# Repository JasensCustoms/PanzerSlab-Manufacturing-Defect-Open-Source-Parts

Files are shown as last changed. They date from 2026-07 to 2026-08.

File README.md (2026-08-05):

<p align="center">
  Jasen's Customs Logo
</p>

# Panzer SLAB — Manufacturing Defect Compatible Parts

Compatible replacement parts for the Panzer SLAB manufacturing defect. This repository holds basic PCB outlines, cable pinouts, and related files. You are welcome to fix errors, add context, and contribute to the repo.

## What's in This Repo

- `Main PCB/` — main PCB design files
- `Plexi Overlay/` — plexi overlay cut file / art template (all SLABs)
- `AUX PCB Files/` — AUX PCB design and production files
- `USB C PCB Files/` — USB-C PCB design and production files
- `3D Printed Parts/` — 3D-printable parts (main PCB fix spacers and taller aux button)

## Community & Discussion

Questions, ideas, or just want to talk builds? Join the Jasen's Customs Discord: [discord.gg/UJmNMunTqa](https://discord.gg/UJmNMunTqa)

## License — Personal, Non-Commercial Use Only

Copyright © 2026 Jasen Hicks ([www.JasensCustoms.com](https://www.JasensCustoms.com)). All rights reserved.

These designs are provided **solely for personal, private, non-commercial use.** You may build units for yourself, modify the designs for your own projects, and share the unmodified files (with attribution and the license intact). You may **not** sell parts, kits, units, or derivatives, manufacture for profit, or use these files commercially in any way.

Full terms — including the **No Warranty** and **No Support** notices — are in [LICENSE.md](LICENSE.md). By downloading, copying, or using any file in this repository, you agree to them.

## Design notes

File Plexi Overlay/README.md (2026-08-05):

# Plexi Overlay

Plexi overlay cut file for the Panzer SLAB. **Works on all SLABs.**

## What's in This Folder

- `panzer-slab.svg` — full overlay outline: all button openings, case outline, and mounting holes

## Material

Use **1.5mm (1/16") plexi/acrylic**.

## Usage

The file works two ways:

- **Direct cutting** — send it straight to a laser cutter or CNC as-is.
- **Art template** — use it as the template layer in your design software to line artwork up with the button openings and case outline before cutting.

## License & Community

Part of the [Panzer SLAB — Manufacturing Defect Compatible Parts](../README.md) repository. Provided for **personal, non-commercial use only** — full terms in [LICENSE.md](../LICENSE.md). Questions? Join the Jasen's Customs Discord: [discord.gg/UJmNMunTqa](https://discord.gg/UJmNMunTqa)

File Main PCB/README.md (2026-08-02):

# Main PCB

The main PCB has the critical placement of the Brook PCB, USB output, AUX PCB connections, OLED connections, and LEDs. Everything is unrouted. The files are provided in Fusion Archive Format. Placement of MX sockets should be at the center of each circle on the PCB to ensure fitment.

## What's in This Folder

- `slab-main-pcb-open-source-unrouted.f3z` — unrouted board, Fusion Archive Format
- `slab-main-pcb-open-source-board-mx-routed.fbrd` — routed MX version
- `slab-main-pcb-open-source-board_2026-07-29.zip` — production files
- `slab-main-pcb-open-source-board_bom.csv` / `slab-main-pcb-open-source-board_cpl.csv` — BOM and component placement (CPL) files

## Parts List (BOM)

Complete parts list from `slab-main-pcb-open-source-board_bom.csv` (LCSC part numbers included for ordering). Use the CPL file for component placement.

| Qty | Part | Designators | Footprint | LCSC # |
|---|---|---|---|---|
| 15 | 0.1µF capacitor | C1–C4, C6–C15, C20 | 0402 | C60474 |
| 15 | SK6812MINI reverse-mount RGB LED | U$4–U$18 | C5149201 | C5149201 |
| 15 | Kailh hot-swap switch socket | SW1–SW15 | SWITCH_SOCKET | C5156480 |
| 2 | 22Ω resistor | R5, R6 | 0805 | C17561 |
| 2 | 500Ω resistor | R3, R4 | 0402 | C227124 |
| 2 | 2x4 header | U$1, U$2 | 2X4 | C225289 |
| 1 | 1x4 right-angle header | JP2 | 1X04/90 | C32713263 |
| 1 | MF-SMDF050 resettable fuse | U$19 | MF-SMDF050 | C210839 |
| 1 | JST S4B-PH-SM4-TB connector (PH, 4-pin, side-entry SMT) | X1 | S4B-PH-SM4-TB | C265102 |
| 1 | USB-302S USB connector | U$20 | USB-302S | C112455 |

### Additional Parts Not on the BOM

- **4x 1x11 2.54mm pitch low-profile machine pin sockets** — required for the Brook PCB mounting area.

## Routed MX Version

> **UNTESTED AS OF 07/29/2026** — please manufacture at your own risk. Download the files and check them yourself as a second check.

Includes a USB key so if someone ever publishes a GP2040 board in the same Gen5X footprint, you can make use of the auth key functionality.

Routed MX main PCB, top view

Routed MX main PCB, bottom view

## License & Community

Part of the [Panzer SLAB — Manufacturing Defect Compatible Parts](../README.md) repository. Provided for **personal, non-commercial use only** — full terms in [LICENSE.md](../LICENSE.md). Questions? Join the Jasen's Customs Discord: [discord.gg/UJmNMunTqa](https://discord.gg/UJmNMunTqa)

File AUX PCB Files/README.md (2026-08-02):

# AUX PCB Files

Design and production files for the SLAB AUX PCB.

## What's in This Folder

- `slab-aux-pcb.brd` / `slab-aux-pcb.sch` — Autodesk EagleCAD board and schematic files
- `slab-aux-pcb_2025-09-11.zip` — production files

## License & Community

Part of the [Panzer SLAB — Manufacturing Defect Compatible Parts](../README.md) repository. Provided for **personal, non-commercial use only** — full terms in [LICENSE.md](../LICENSE.md). Questions? Join the Jasen's Customs Discord: [discord.gg/UJmNMunTqa](https://discord.gg/UJmNMunTqa)

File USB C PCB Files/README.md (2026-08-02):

# USB C PCB Files

Design and production files for the SLAB USB-C PCB.

## What's in This Folder

- `usb-c-pcb.brd` / `usb-c-pcb.sch` — Autodesk EagleCAD board and schematic files
- `usb-c-pcb_2025-09-19.zip` — production files

## License & Community

Part of the [Panzer SLAB — Manufacturing Defect Compatible Parts](../README.md) repository. Provided for **personal, non-commercial use only** — full terms in [LICENSE.md](../LICENSE.md). Questions? Join the Jasen's Customs Discord: [discord.gg/UJmNMunTqa](https://discord.gg/UJmNMunTqa)

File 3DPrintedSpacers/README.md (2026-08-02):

# 3D Printed Spacers

3D printed spacers that fit over the machined posts on the case to space the main PCB at the correct distance from the top panel.

## What's in This Folder

- `SLABMainPCBFixSpacers-V1.0.3MF` — all spacer parts in a single 3MF file (V1.0)

## Printing Guidance

Print in **PETG** with thick walls — 4 wall loops works great.

Print the following quantities:

- **2x** D-shaped spacers
- **1x** irregularly shaped circle spacer
- **7x** circle spacers

## License & Community

Part of the [Panzer SLAB — Manufacturing Defect Compatible Parts](../README.md) repository. Provided for **personal, non-commercial use only** — full terms in [LICENSE.md](../LICENSE.md). Questions? Join the Jasen's Customs Discord: [discord.gg/UJmNMunTqa](https://discord.gg/UJmNMunTqa)

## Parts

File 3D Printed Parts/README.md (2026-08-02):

# 3D Printed Parts

3D-printable parts for the Panzer SLAB manufacturing defect fix.

## What's in This Folder

- `SLABMainPCBFixSpacers-V1.0.3MF` — main PCB fix spacers, all parts in a single 3MF file (V1.0)
- `SLAB - AuxButtonTaller.STL` — taller aux button

## Spacers

The spacers fit over the machined posts on the case to space the main PCB at the correct distance from the top panel.

Print in **PETG** with thick walls — 4 wall loops works great.

Print the following quantities:

- **2x** D-shaped spacers
- **1x** irregularly shaped circle spacer
- **7x** circle spacers

## License & Community

Part of the [Panzer SLAB — Manufacturing Defect Compatible Parts](../README.md) repository. Provided for **personal, non-commercial use only** — full terms in [LICENSE.md](../LICENSE.md). Questions? Join the Jasen's Customs Discord: [discord.gg/UJmNMunTqa](https://discord.gg/UJmNMunTqa)

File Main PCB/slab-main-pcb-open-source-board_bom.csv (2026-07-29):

Comment | Designator | Footprint | LCSC Part #
 | JP2 | 1X04/90 | C32713263
.1uF | C1 C2 C3 C4 C6 C7 C8 C9 C10 C11 C12 C13 C14 C15 C20 | C0402K | C60474
2X4 | U$1 U$2 | 2X4 | C225289
22 | R5 R6 | R0805 | C17561
500 | R3 R4 | R0402 | C227124
C5149201-SK6812MINI | U$4 U$5 U$6 U$7 U$8 U$9 U$10 U$11 U$12 U$13 U$14 U$15 U$16 U$17 U$18 | C5149201-REVERSEMOUNTLED | C5149201
KAILH_SWITCH_SOCKET | SW1 SW2 SW3 SW4 SW5 SW6 SW7 SW8 SW9 SW10 SW11 SW12 SW13 SW14 SW15 | SWITCH_SOCKET | C5156480
MF-SMDF050 | U$19 | MF-SMDF050 | C210839
S4B-PH-SM4-TB | X1 | S4B-PH-SM4-TB | C265102
USB-302S | U$20 | USB-302S | C112455

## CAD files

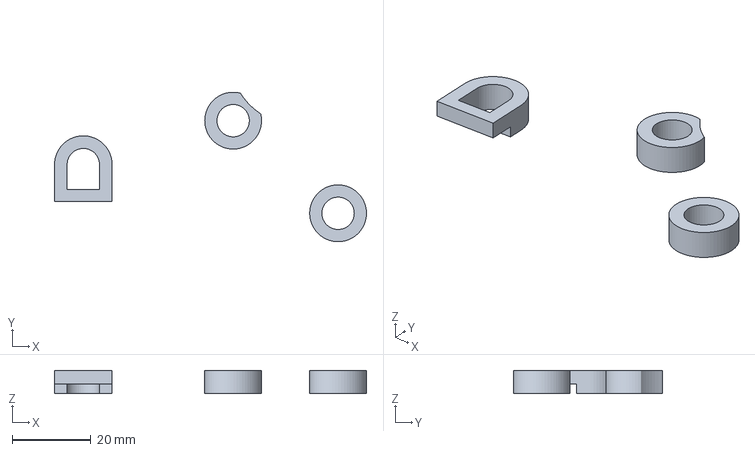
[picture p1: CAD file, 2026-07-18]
3D Printed Parts/SLABMainPCBFixSpacers-V1.0.3MF
79.0 x 37.9 x 5.90 mm

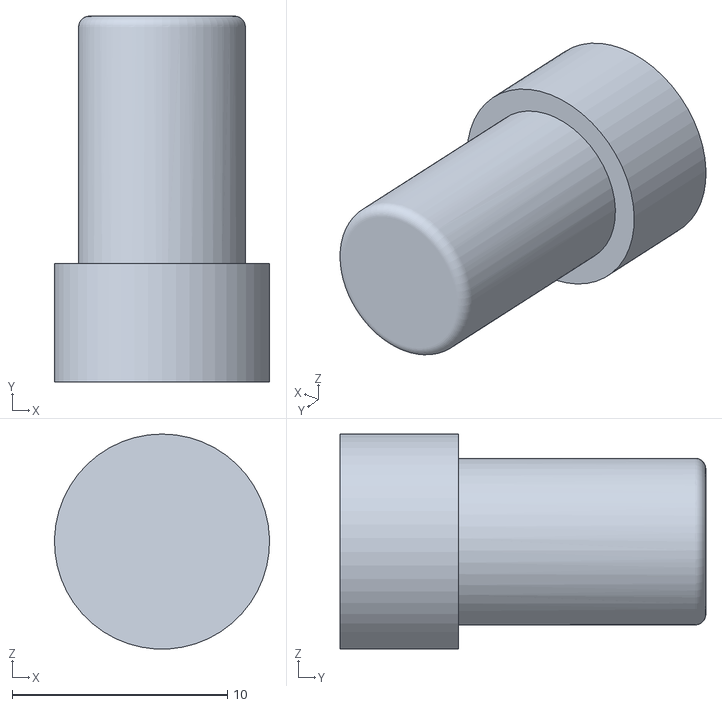
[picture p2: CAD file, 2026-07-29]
3D Printed Parts/SLAB - AuxButtonTaller.STL
9.99 x 17.0 x 9.99

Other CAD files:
Main PCB/slab-main-pcb-open-source-unrouted.f3z

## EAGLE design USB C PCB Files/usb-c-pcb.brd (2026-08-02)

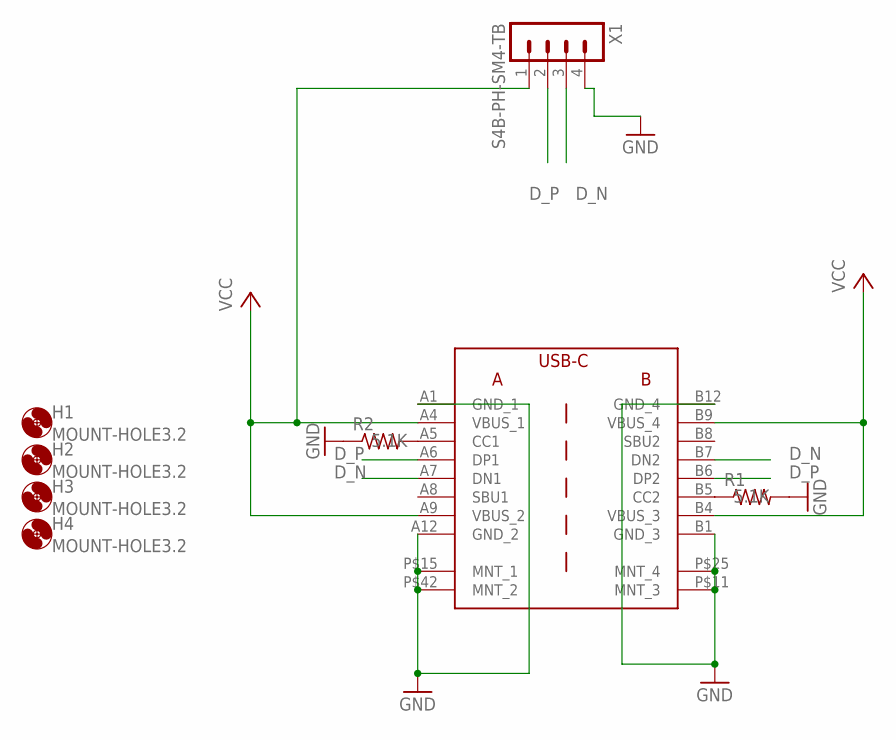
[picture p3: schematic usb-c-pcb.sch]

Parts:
H1, H2, H3, H4: MOUNT-HOLE3.2; 3,2
R1, R2: 5.1K; R0402
U$1: USB_TAYPE_C_16P
X1: S4B-PH-SM4-TB

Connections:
D_N: U$1.A7 (DN1), U$1.B7 (DN2), X1.3
D_P: U$1.A6 (DP1), U$1.B6 (DP2), X1.2
GND: R1.2, R2.1, U$1.A1 (GND_1), U$1.A12 (GND_2), U$1.B1 (GND_3), U$1.B12 (GND_4), U$1.P$11 (MNT_3), U$1.P$15 (MNT_1), U$1.P$25 (MNT_4), U$1.P$42 (MNT_2), X1.4
unnamed: R1.1, U$1.B5 (CC2)
unnamed: R2.2, U$1.A5 (CC1)
VCC: U$1.A4 (VBUS_1), U$1.A9 (VBUS_2), U$1.B4 (VBUS_3), U$1.B9 (VBUS_4), X1.1

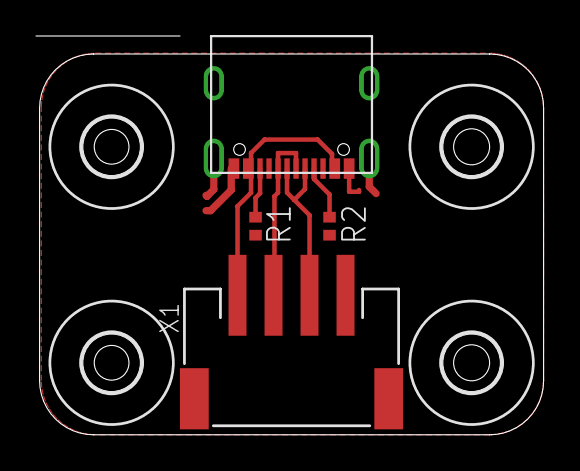
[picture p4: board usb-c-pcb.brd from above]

Board: 2 copper layers, 28.2 x 22.2 mm, 8 parts (0 on the bottom side), 6 nets.

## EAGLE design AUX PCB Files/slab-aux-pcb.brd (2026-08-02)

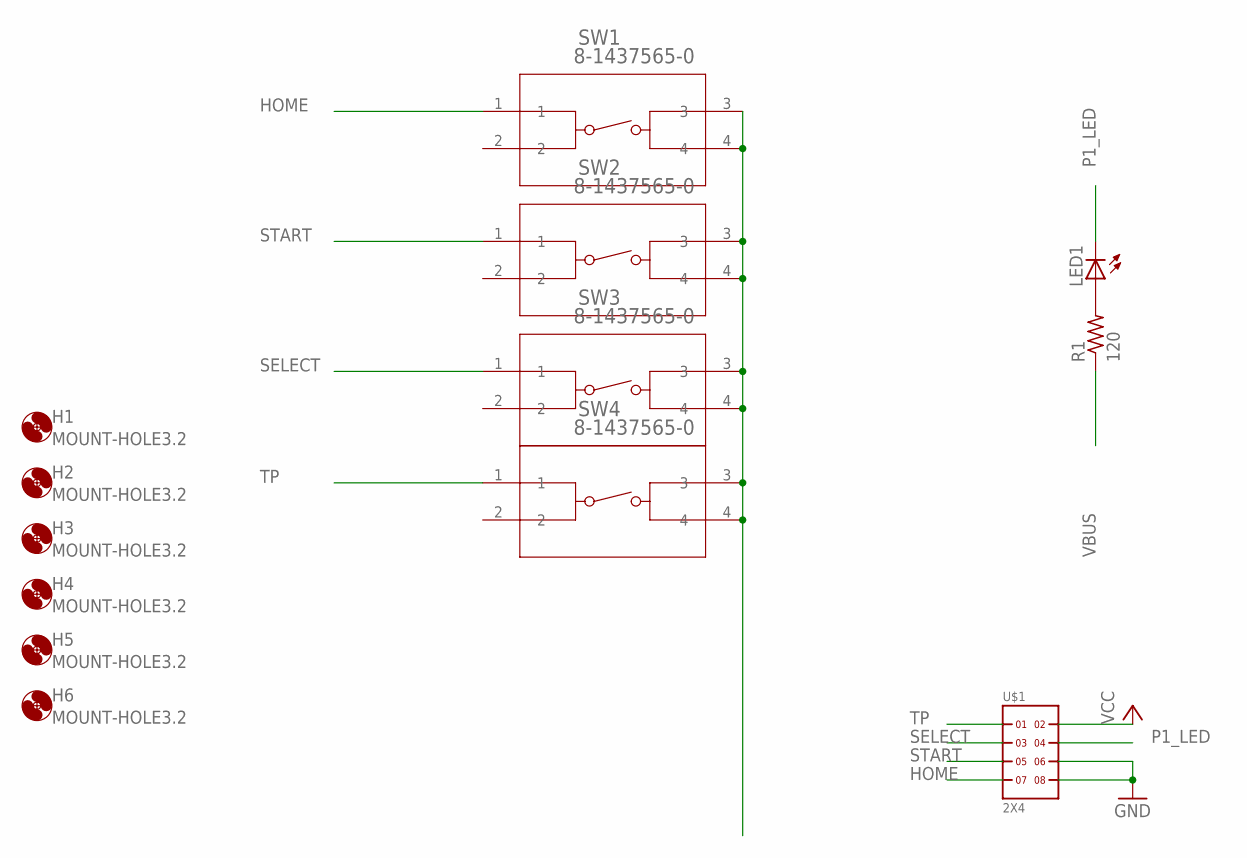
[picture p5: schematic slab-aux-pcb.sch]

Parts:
H1, H2, H3, H4, H5, H6: MOUNT-HOLE3.2; 3,2
LED1: LEDCHIP-LED0603; CHIP-LED0603
R1: 120; R0603
SW1, SW2, SW3, SW4: 8-1437565-0; SW4_1437565
U$1: 2X4

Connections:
GND: SW1.3, SW1.4, SW2.3, SW2.4, SW3.3, SW3.4, SW4.3, SW4.4, U$1.6, U$1.8
HOME: SW1.1, U$1.7
unnamed: LED1.A, R1.2
P1_LED: LED1.C, U$1.4
SELECT: SW3.1, U$1.3
START: SW2.1, U$1.5
TP: SW4.1, U$1.1
VBUS: R1.1, U$1.2

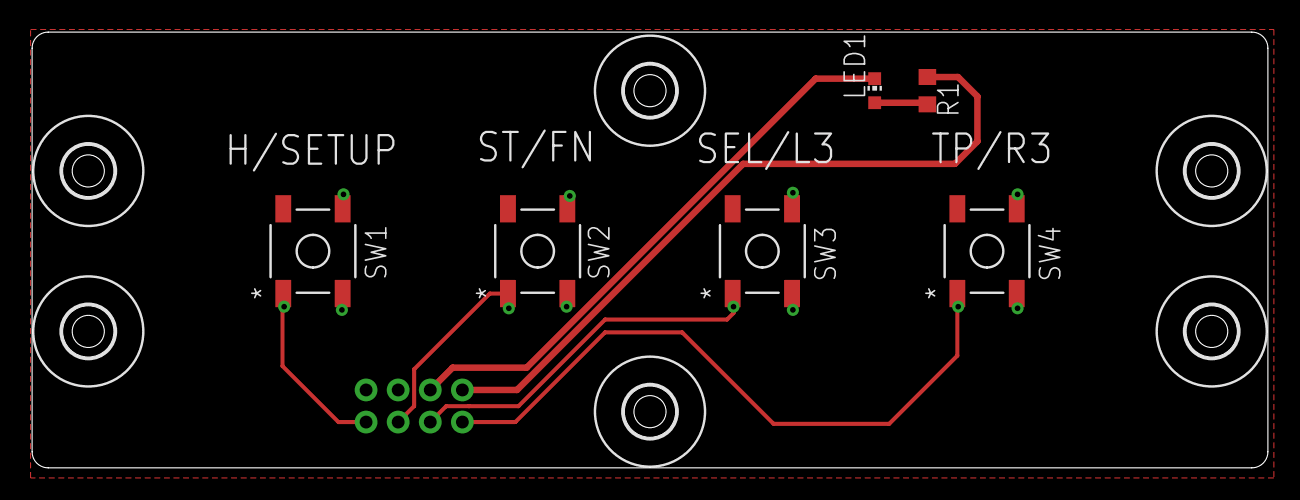
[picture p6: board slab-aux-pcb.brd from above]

Board: 2 copper layers, 77.0 x 27.2 mm, 13 parts (1 on the bottom side), 8 nets.

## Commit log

2026-07-18 Add readme for main PCB details and connections
    Added a description for the main PCB layout and connections.
2026-07-18 Add description for 3D printed spacers
2026-07-18 Update readme with printing specifications
    Added printing material and wall thickness recommendation.
2026-07-18 Add files via upload
    Base spacers that need to be 3D printed in 3MF format.
    [SLABMainPCBFixSpacers-V1.0.3MF]
2026-07-18 Update readme with spacer printing instructions
    Added printing instructions for 3D printed spacers.
2026-07-29 Add files via upload
    5mm taller AUX buttons to support mis-manufactured SLAB cases.
    [SLAB - AuxButtonTaller.STL]
2026-07-29 Add files via upload
    Fusion PCB file archive, BOM, CPL, and JLC PCB Gerber Files.
    [slab-main-pcb-open-source-board_bom.csv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]
2026-08-02 Add structured README.md files for each subfolder
    Consistent with the repo-wide README style: contents list, build/print
    guidance, and license/community footer.
    Claude-Session: https://claude.ai/code/session_013JLHN2qqf5r5F5bnh4qKFf
2026-08-02 Add AUX PCB and USB-C PCB files; consolidate 3D printed parts
    New AUX PCB Files and USB C PCB Files folders with EagleCAD and
    production files. 3D-printable parts (spacers + taller aux button)
    consolidated into 3D Printed Parts, replacing 3DPrintedSpacers and
    the root STL. README.md added for each new folder; root README
    updated to match.
    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
    [SLAB - AuxButtonTaller.STL, SLABMainPCBFixSpacers-V1.0.3MF, slab-aux-pcb.brd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]
2026-08-02 Add complete parts list to Main PCB README
    Full BOM table with quantities, designators, footprints, and LCSC
    part numbers, plus a note that 4x 1x11 2.54mm low-profile machine
    pin sockets are required for the Brook PCB mounting area.
    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
2026-08-05 Add Plexi Overlay folder with README
    SVG overlay cut file for all SLABs; use 1.5mm (1/16") plexi. Good
    for direct cutting or as an art template. Root README updated.
    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

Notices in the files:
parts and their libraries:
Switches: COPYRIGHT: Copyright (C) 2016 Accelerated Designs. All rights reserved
